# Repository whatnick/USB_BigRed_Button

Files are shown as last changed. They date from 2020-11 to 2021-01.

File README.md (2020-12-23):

# KiCAD port of USB Big Red Button Project
- Imported from Eagle version of files on 28/11/2020
- Added STL enclosure / PCB carries 24/12/2020
- For mechanical designs in Fusion 360 refer to original repository
- For software refer to original repository

## Renders

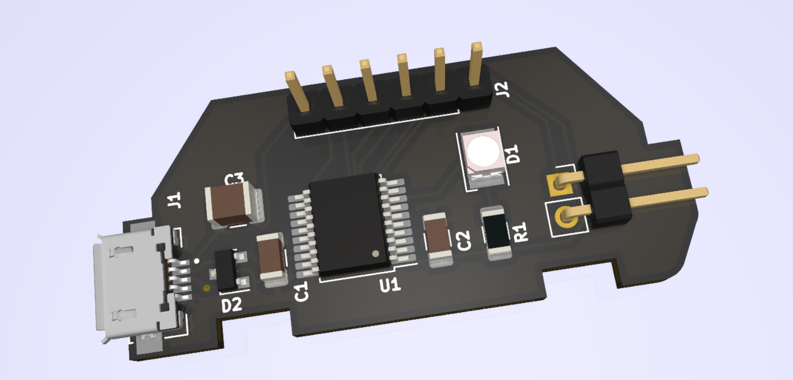
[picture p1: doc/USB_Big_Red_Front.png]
PCB Front


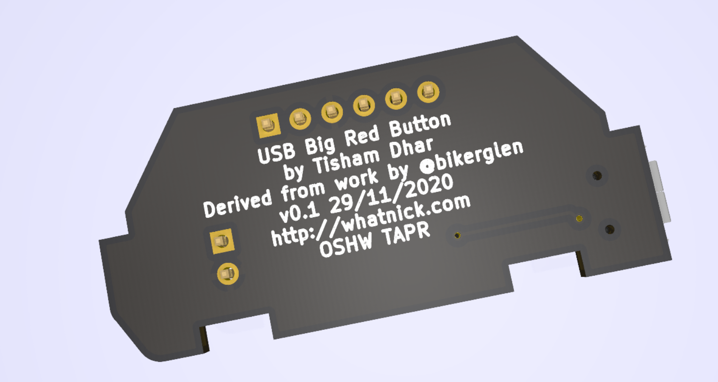
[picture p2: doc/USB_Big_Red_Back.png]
PCB Back


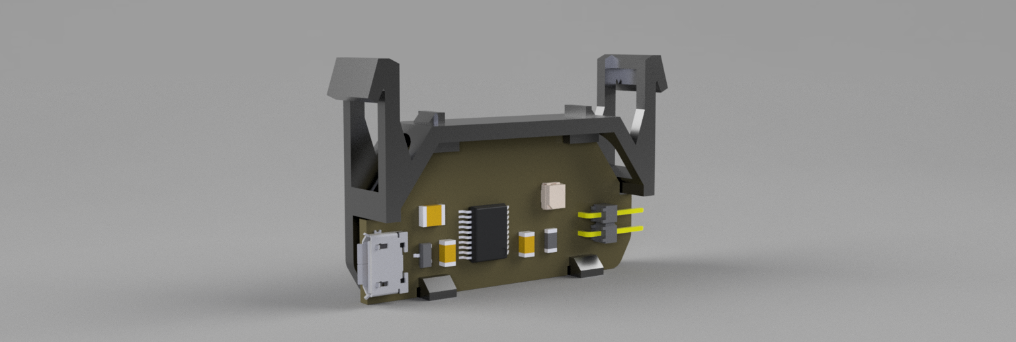
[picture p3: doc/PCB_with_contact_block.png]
PCB in Carrier


## Direct Order for PCB/BOM

- Order PCB via [OSHPark](https://oshpark.com/shared_projects/303OZMds)
- Order BOM via [Digikey](https://digikey.com.au/short/z10044)

## Credits

- Original design by [@bikerglen](https://twitter.com/bikerglen)
- KiCAD port by [@whatnick](https://twitter.com/whatnick)
- 3D prints by [@tweety_belle](https://twitter.com/tweety_belle) and [SANE Makerspace](http://www.sanemakerspace.com/)

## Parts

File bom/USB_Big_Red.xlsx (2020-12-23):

References | manf# | Value | Footprint | Quantity
C2 | C1206C104K5RAC7800 | 0.1uF 50V | C_1206_3216Metric | 1
C3 | C1210F105K4RACTU | 1uF 16V X5R | C_1210_3225Metric | 1
C1 | CAP CER 0.47UF 50V X7R 1206 | 0.47uF 50V | C_1206_3216Metric | 1
R1 | RT1206FRE071KL | 1k | R_1206_3216Metric | 1
D1 | AA3528SURSK | LEDKA-3528ASYC | LED_PLCC-2 | 1
D2 | TPD2E2U06QDBZRQ1 | TPD2E2U06QDBZRQ1 | SOT-23 | 1
U1 | PIC16F1459T-I/SS | PIC16F1459-I_SS | SSOP-20_5.3x7.2mm_P0.65mm | 1
J1 | 629105136821 | 629105136821 | WE_629105136821 | 1

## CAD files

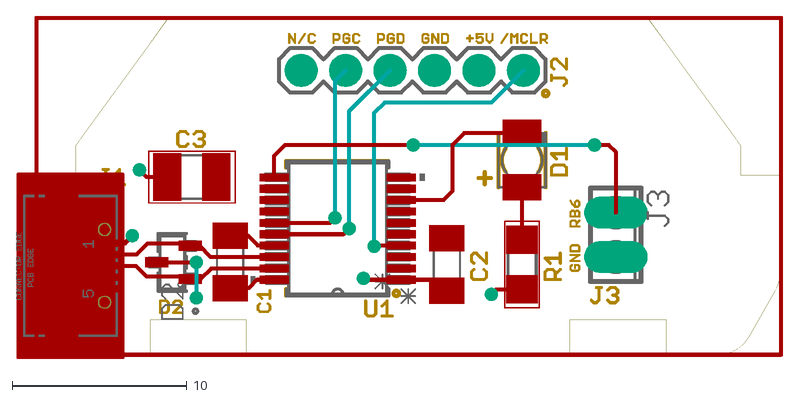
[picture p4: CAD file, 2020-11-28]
contact-block-v4.dxf
43.8 x 19.6

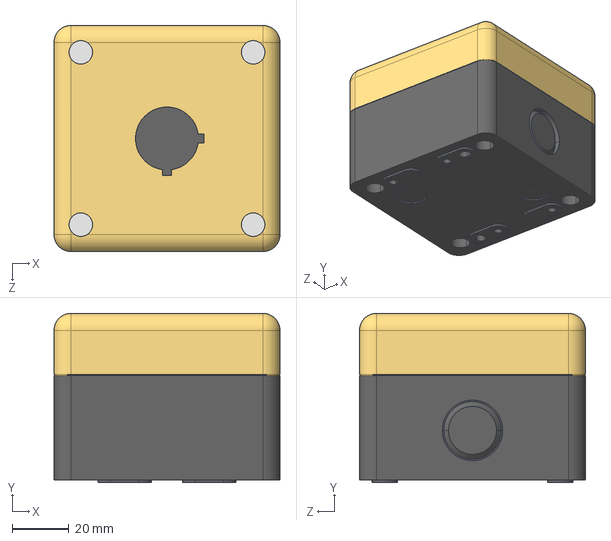
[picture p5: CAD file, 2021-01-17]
enclosure/A22NZ_A_B01Y.step
80.0 x 59.9 x 80.0 mm

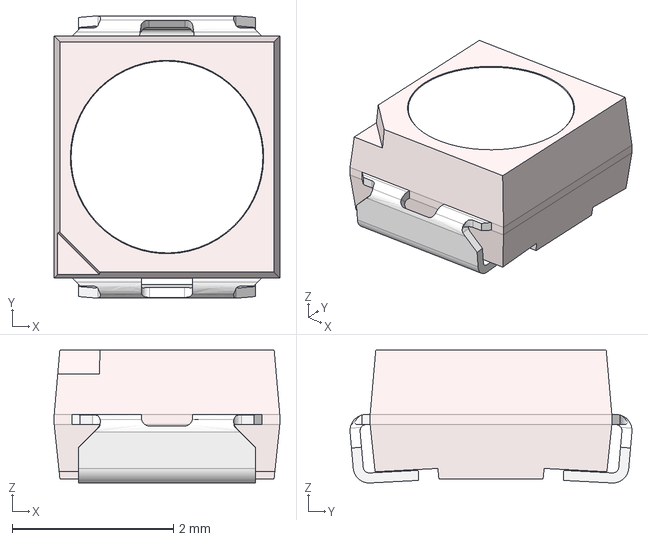
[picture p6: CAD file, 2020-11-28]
3dmodels/LED PLCC-2.stp
2.80 x 3.50 x 1.65 mm

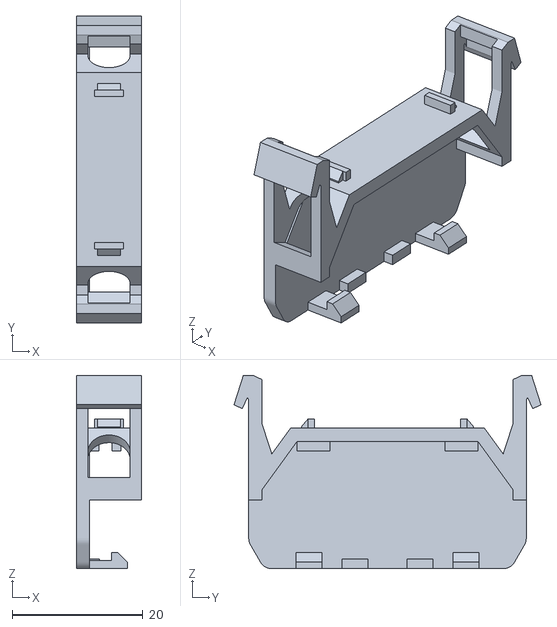
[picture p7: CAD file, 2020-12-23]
enclosure/contact-block-clip-in-board-knubs-2mm-back-gap v1.stl
9.90 x 47.0 x 29.6

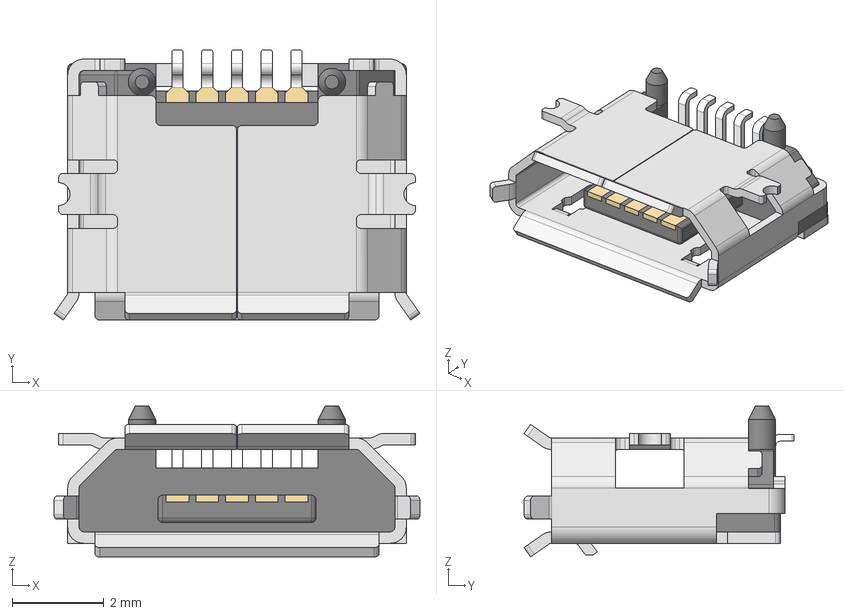
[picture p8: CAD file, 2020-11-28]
3dmodels/629105136821.stp
8.00 x 5.90 x 3.30 mm
Shielding
Insulator
Pin x 5

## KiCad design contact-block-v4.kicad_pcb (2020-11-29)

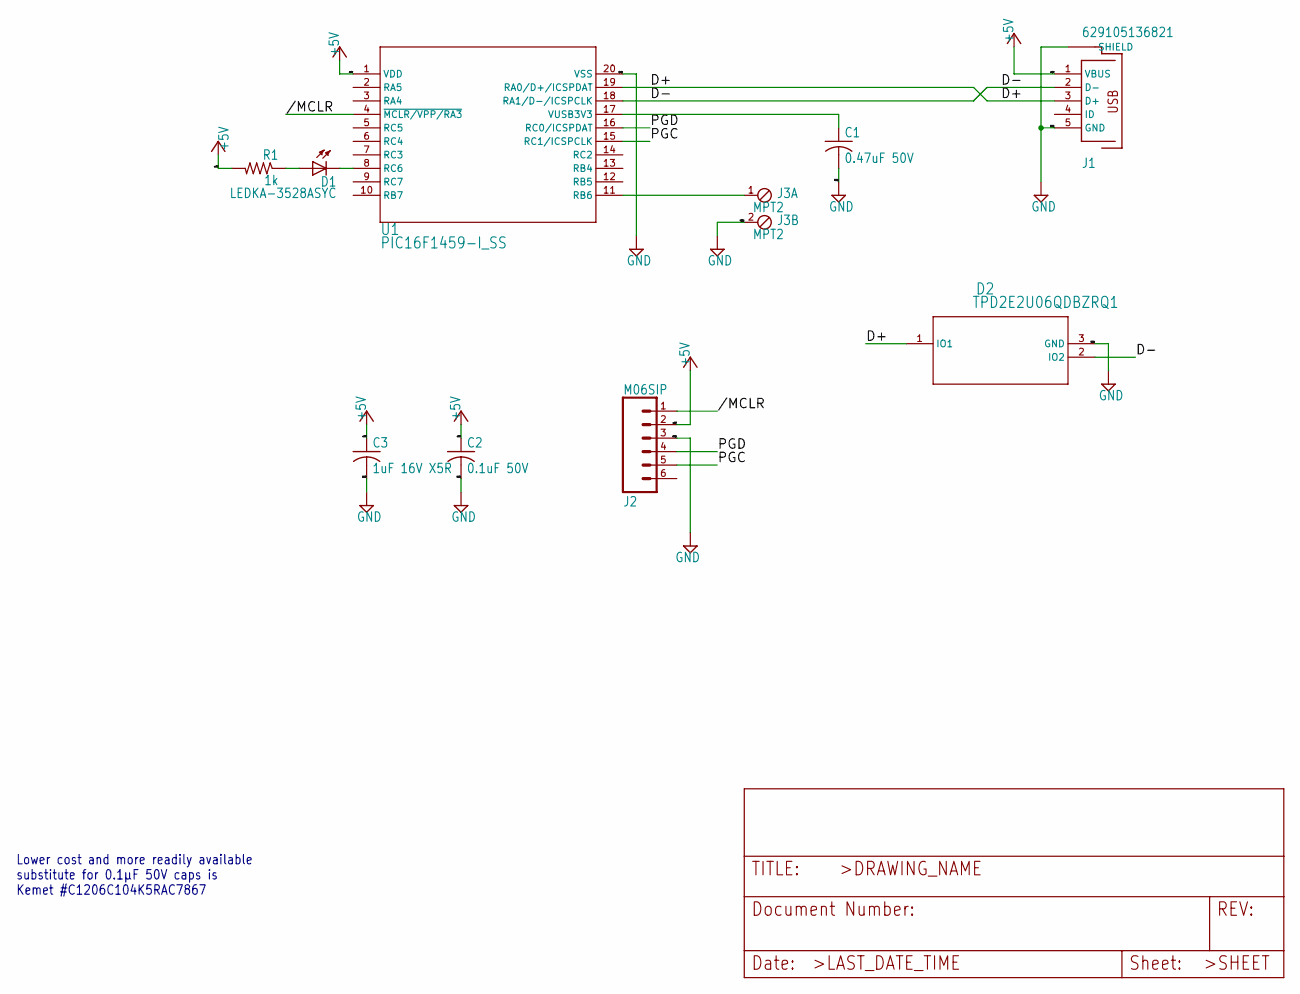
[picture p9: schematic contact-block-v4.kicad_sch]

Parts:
C1: C1206C474K5RACTU; C_1206_3216Metric
C2: C1206S104M5RACTU; C_1206_3216Metric
C3: C1210C105K4PACTU; C_1210_3225Metric
D1: LEDKA-3528ASYC; LED_PLCC-2
D2: TPD2E2U06QDBZRQ1; SOT-23
J1: 629105136821; WE_629105136821
J2: M06SIP; PinHeader_1x06_P2.54mm_Vertical
J3: MPT2; PinSocket_1x02_P2.54mm_Vertical
R1: CR1206-JW-102ELF; R_1206_3216Metric
U1: PIC16F1459-I_SS; SSOP-20_5.3x7.2mm_P0.65mm

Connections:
+5V: C2.1, C3.1, J1.1 (VBUS), J2.2, R1.2, U1.1 (VDD)
/D+: D2.1 (IO1), J1.3 (D+), U1.19 (RA0/D+/ICSPDAT)
/D-: D2.2 (IO2), J1.2 (D-), U1.18 (RA1/D-/ICSPCLK)
/PGC: J2.5, U1.15 (RC1/ICSPCLK)
/PGD: J2.4, U1.16 (RC0/ICSPDAT)
//MCLR: J2.1, U1.4 (~MCLR/VPP/RA3)
GND: C1.2, C2.2, C3.2, D2.3 (GND), J1.5 (GND), J1.S1 (SHIELD), J1.S2 (SHIELD), J1.S3 (SHIELD), J1.S4 (SHIELD), J2.3, J3.2 (1), U1.20 (VSS)
unnamed: C1.1, U1.17 (VUSB3V3)
unnamed: D1.1 (A), R1.1
unnamed: D1.2 (C), U1.8 (RC6)
unnamed: J3.1, U1.11 (RB6)

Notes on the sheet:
Lower cost and more readily available substitute for 0.1µF 50V caps is Kemet #C1206C104K5RAC7867

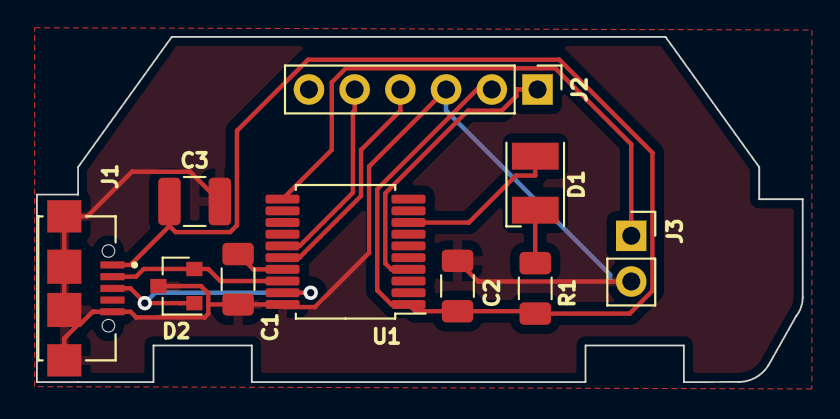
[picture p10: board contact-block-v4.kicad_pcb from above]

Board: 2 copper layers, 42.5 x 19.2 mm, 10 parts (0 on the bottom side), 11 nets.

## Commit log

2020-11-28 Initial import
    [contact-block-v4.dxf, contact-block-v4.kicad_pcb, contact-block-v4.kicad_sch]
2020-11-28 Complete routing and add 3d models
    [629105136821.stp, LED PLCC-2.stp, contact-block-v4.kicad_pcb]
2020-11-28 Save schematic changes
    [contact-block-v4.kicad_sch]
2020-11-28 Add doc images and bom
    [contact-block-v4.kicad_pcb]
2020-11-29 Add parts and gerbers
    [contact-block-v4-B_Cu.gbl, contact-block-v4-B_Mask.gbs, contact-block-v4-B_Paste.gbp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]
2020-12-23 Add enclosure/render/BOM
    [USB_Big_Red.xlsx, contact-block-clip-in-board-knubs-2mm-back-gap v1.stl]
2021-01-17 Some updates and enclosure step
    [A22NZ_A_B01Y.step]
